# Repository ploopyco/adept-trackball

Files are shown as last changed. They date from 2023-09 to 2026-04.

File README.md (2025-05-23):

# The Ploopy Adept Trackball

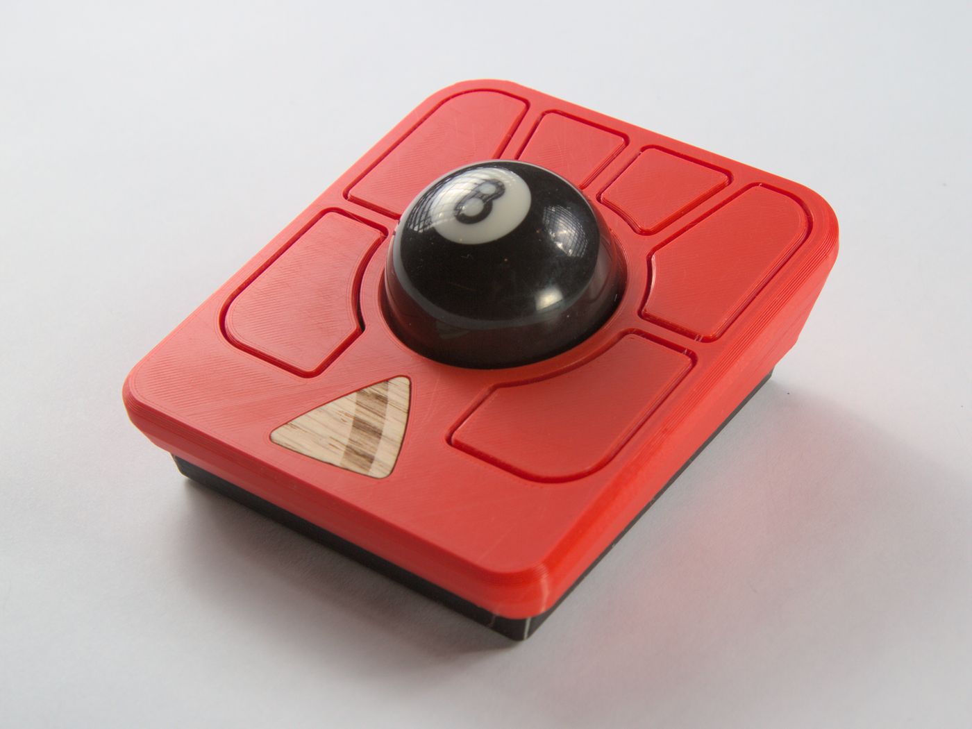
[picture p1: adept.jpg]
The Ploopy Adept Trackball


By some stroke of luck, you've made your way here. The Ploopy Adept Trackball. Your life will never be the same.

This repository contains all of the design and production files necessary to make a Ploopy Adept Trackball. We've also included some [kick-ass documentation](https://ploopyco.github.io/adept-trackball) on how to get it made, assemble it, and program it.

What are you waiting for? Your new life awaits.

## QMK?!

Kits bought from the [Ploopy store](https://ploopy.co/product-category/trackball/adept/) come with QMK and VIA preloaded. [Check out the Wiki](https://ploopyco.github.io/adept-trackball) for instructions on how to load new firmware onto your device. (It's super easy!)

The firmware hex file that ships with all Adepts is included in this repository as well, as `ploopyco_madromys_rev1_001_via.uf2`.

## Under what license is this released?

As per QMK's licensing requirements, the firmware for the Ploopy Adept Trackball is released under GPLv3. Hardware design files, including electronics and mechanical files, are released under OHL CERN v2-S. Check the respective directories for full license text.

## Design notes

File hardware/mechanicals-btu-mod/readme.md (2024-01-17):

## Ploopy Adept BTU Mod by bomtarnes ([keyboard-magpie](https://github.com/keyboard-magpie/))
Included are two print files- 

 - adept-btu-plate.3mf - this includes an integrated support enforcer- I recommend organic supports and "for support enforcers only in prusaslicer
 - adept-btu-top-v1.stl - old fashioned STL for doing as you wish with

Also included is a step file, and a fusion 360 export (my CAD is all self taught and very messy, timeline wise, sorry).

The intended BTUs for v1 are [these veichu ones](https://www.aliexpress.com/item/1005003066404497.html) in 7.5 size.

I am actively working on other versions for other BTU varieties and will aim to add these in the future.

Please do not contact the core ploopy team for any issues with this mod, I can be reached through my github account linked above or on discord.

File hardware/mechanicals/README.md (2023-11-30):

## Only one file? Where are the parts?

The STEP/STL files contain all of the Adept trackball plastic parts in one file. Doing it this way preserves the assembly information, showing how the parts are supposed to fit together, as well as the expected clearances between parts. It also bundles all of the parts for a given revision together, so there's no accidental mixing of parts from different revisions.

## How do I print this?

You'll need to split the parts in the file up before you can print them. Most slicers can do this; if you have a compatible printer we recommend PrusaSlic3r, since that's the one we use in-house and have checked.

Note that submitting this file to some 3rd party print services will cause confusion, as they are expecting one body instead of many. To do this, you can use PrusaSlic3r to split the parts and then export each separately as an STL.

## How can I use the included .3mf file?

The .3mf file was generated using PrusaSlicer v2.5. The job was generated for Prusa i3 MK2S/MK3S/MK3S+ printers. It assumes the use of PLA that is printable at 200-230C. If you have that PrusaSlicer version, such a printer, and such filament, then you're in a lot of luck! We use a .3mf job that is very similar to this one to print Adepts on our printing farm.

If you do not, then using the included .3mf file is likely going to cause you a lot of headaches. If this is the case, the included .3mf file should be considered **as a reference only**. If you use it at all, it is recommended that you look at it to see what kinds of print settings we use (gyroid infill, 0.3mm layer height, part orientation, etc.). However, you should use your own slicing software to generate the .gcode files for your printer.

## Why don't you include a .gcode file?

For your safety. Uploading a .gcode file onto a printer can be extremely hazardous if that .gcode file wasn't specifically generated for that printer. We don't want to come anywhere near that sort of scenario, so we are not going to upload a .gcode file.

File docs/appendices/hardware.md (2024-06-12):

# Appendix C: Hardware

# Buying hardware from us

Getting all of the hardware on your own can be tricky because the parts you select may not fit perfectly. [That's why we sell kits with everything you need to build a Ploopy Adept Trackball](https://ploopy.co/product-category/trackball/adept/). Here's why that's great for you:

- Everything is guaranteed to fit together perfectly
- Everything is guaranteed to work as intended
- You'll end up saving money - probably quite a bit of money - by not spending on extra parts

Your call. You'll sort it out.

# Getting your own hardware

This guide was a bit light on detail in the other sections, and that's because the hardware has to conform to many specifications. They'll all be listed here.

First, a complete list of all the hardware you'll need:

- 4x Small Screws
- 3x MR63ZZ Roller Bearings
- 4x Friction Pads
- 1x Snooker Ball

We'll be going over all of them in detail. There will be mentions of *critical specifications*; if you're going to be sourcing your own parts, **you must get parts that conform to the critical specifications**. If you go off-menu, the parts will not fit the way that we intended when we designed the trackball. That might mean that your trackball **doesn't work**.

Let's get cracking.

## Small Screws

Here are the critical specifications:

- \#2
- 3/8" length

## MR63ZZ Roller Bearings
Here are the critical specifications:

- MR63ZZ bearing
- 3mm inner diameter
- 6mm outer diameter
- 2.5mm thickness

## Friction pads
Here are the critical specifications:

- Circular shape
- Up to 3/4" diameter
- Up to 1/8" thickness
- Non-slip

## Snooker ball
We use 1.75-inch diameter (44.45mm) miniature snooker balls. Any ball between 44.0mm and 44.6mm will work.

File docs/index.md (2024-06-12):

# Home

So, you want to build a Ploopy Adept Trackball, eh? Or, maybe you want to replace some broken parts. Maybe you want to reprogram it. Or maybe you just want to know how it all works. No matter the motivation, this is the place to learn.

**Bought a kit and itching to get it built?** --> Get started by going to the [assembly instructions](assembly-instructions.md).

**Looking to purchase a kit with everything you need to build your own Ploopy Adept?** --> [Check out the Ploopy store](https://ploopy.co/product-category/trackball/adept/).

**Building a Ploopy Adept Trackball from scratch?** --> Get started by going to [Appendix A: Printed circuit boards](appendices/pcbs.md).

---

*Copyright (C) 2023 Ploopy Corporation. Permission is granted to copy, distribute and/or modify this document under the terms of the GNU Free Documentation License, Version 1.3 or any later version published by the Free Software Foundation; with no Invariant Sections, no Front-Cover Texts, and no Back-Cover Texts. A copy of the license is included in the section entitled "GNU Free Documentation License".*

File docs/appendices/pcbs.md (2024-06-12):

# Appendix A: Printed circuit boards

## Buying boards from us
Getting the Ploopy boards made can be complex, and expensive, especially if you only need one set. [That's why we sell kits with everything you need to build a Ploopy Adept Trackball](https://ploopy.co/product-category/trackball/adept/). Here's why that's great for you:

- You get a PCB with all components soldered
- The firmware is already programmed on the microcontroller, so you won't have to program it
- It'll cost a hell of a lot less than if you do a production run of PCBs just for yourself
- You won't have to order components and wait while they come in
- We guarantee that it works

Just something to consider. You're smart. You'll figure it out.

## Making your own boards

Want to make your own Ploopy Adept Trackball boards? Great! Less work for us. Seriously, though, only choose this option if you know what you're doing. You don't want to embarrass yourself, do you?

### Step 1: Order the PCBs from a PCB production company

Here are the most important configurations you'll need to communicate to the company:

- 4 layers
- FR-4, TG 150-160 (basically, whatever the cheapest option is)
- 0.8mm thickness
- 6/6mil track/spacing distance
- 0.3mm minimum hole size
- ENIG surface finish, but you can go with HASL if you don't care about lead poisoning
- 1oz copper thickness for both outer and inner layers
- Choose whatever colours you want for solder mask and silkscreen; we like white solder mask and black silkscreen

If something is missing from here, it's not really important.

At some point, you'll have to upload design files to the production company. Use the [electronics source files](https://github.com/ploopyco/adept-trackball/tree/master/hardware/electronics) to generate manufacturing files (you'll have to convert them from their native Altium format if you're using some other platform). That should contain everything you need to get the boards made. If the production company rejects this package, however, you'll need to address the issue yourself.

### Step 2: Order the electronics components

All of the components are described in the schematics of the PCBs. Ordering the components is left as an exercise for the reader.

A complete list of all of the components can be found in the electrical design files.

### Step 3: Get the necessary tools

- PCB
- All of the electronics components
- A soldering iron
- Solder
- A printout of the schematics

### Step 4: Solder the components to the boards

Once you've got the PCBs and all of the components, print out the schematics. Use the schematics to match the reference designators on the PCBs to the reference designators on the schematics, and then get to soldering.

If you've never soldered surface mount components before, or want a refresher on how to solder, we recommend [this video on using an iron to solder surface mount components](https://www.youtube.com/watch?v=3NN7UGWYmBY), and [this video on using a hot-air soldering station](https://www.youtube.com/watch?v=c_Qt5CtUlqY).

Lastly, you'll need to follow a set of special instructions to assemble the PMW3360 sensor and the optic. [Take a look at page 11 of the official PMW3360 datasheet to find out how to do this](https://d3s5r33r268y59.cloudfront.net/datasheets/9604/2017-05-07-18-19-11/PMS0058-PMW3360DM-T2QU-DS-R1.50-26092016._20161202173741.pdf) (page 8 has visuals, for those of you who like purdy pictures).

**MAKE SURE THAT THE PMW3360 IS ORIENTED CORRECTLY BEFORE YOU SOLDER IT!** This is a really easy step to mess up, so *DOUBLE-CHECK IT!*

### Step 5: All done!

Congrats, you finished assembling the electronics! Pat yourself on the back.

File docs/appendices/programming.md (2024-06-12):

# Appendix D: QMK Firmware Programming

# Working with QMK

Ploopy devices are fairly easy to program and reprogram, thanks to the excellent work by all of the developers and maintainers of the [QMK firmware suite](https://github.com/qmk/qmk_firmware).

## Madromys? What's that?

`madromys` is our internal codename for the Ploopy Adept. We don't always know what we're going to call the devices as we're designing them, so we assign codenames to them. This naming convention is also present in some public places, such as the QMK repository. If you see `madromys` while you're working with QMK, just know that the Adept and `madromys` are the same thing.

## Before you begin

If you have never used QMK before, go through [all of the steps in the QMK guide to set up your environment](https://docs.qmk.fm/#/newbs_getting_started).

QMK was built for keyboards, so you'll see lots of references to code that looks like the following:

`-kb <keyboard>`

Whenever you see that, use the following syntax:

`-kb ploopyco/madromys/rev1_001`

and you'll be fine.

## Building the Ploopy device firmware

With your terminal window open and pointed at your QMK build environment, compile the firmware with the following command:

`qmk compile -kb ploopyco/madromys/rev1_001 -km via`

Alternatively, you can invoke the Makefile directly with the following:

`make ploopyco/madromys/rev1_001:via`

If you wish, you can use the default keymap (with `qmk compile -kb ploopyco/madromys/rev1_001 -km default` or `make ploopyco/madromys/rev1_001:default`). However, the VIA keymap is particularly interesting because it allows for customization of the trackball's functions without reflashing the firmware, through the use of the convenient [VIA software package](https://github.com/the-via/releases/releases). It's incredibly handy, so definitely check it out.

For more details on building QMK firmware in general, see the [QMK firmware guide](https://docs.qmk.fm/#/newbs_building_firmware).

## Putting the Ploopy device into bootloader mode

Putting the Ploopy device into bootloader mode is very easy.

1. Unplug it from your computer.
2. Hold down the Bottom Left button on the Adept.
3. Plug the Ploopy device into your computer.
4. The computer should recognise that a mass storage device was just plugged in. Once this is done, you should be able to drag and drop files onto the Ploopy device, as if the board was a USB drive. Feel free to remove the tweezers or paperclip at this point.

And that's it. While plugged in this way, the Ploopy device will accept new firmware.

If you want to upload a new firmware file (a ".uf2" file, like "ploopy_adept_v42069" or something), just drag it into the folder, and it'll automatically install on the Ploopy device and restart itself.

Whenever you want to put new firmware onto the Ploopy device, go through these steps again.

**TIP**: If your firmware is in some kind of strange state and uploading new firmware isn't fixing it, try uploading [a flash nuke](https://learn.adafruit.com/getting-started-with-raspberry-pi-pico-circuitpython/circuitpython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) to the Adept before flashing the new firmware. It wipes the memory of the Adept completely clean, which can help clear a few types of errors.

## Putting the Ploopy device into bootloader mode if it's bricked

Putting the Ploopy device into bootloader mode if it's bricked is a bit more involved, but still doable.

1. Unplug it from your computer.
2. Open it by removing the screws in the base and removing the top.
3. Look for a pair of vias (gold-plated holes) on the board. You can see where they're located [in this photo](https://ploopy.co/wp-content/uploads/2023/11/boot.jpg).
4. Get a paper clip (non-insulated, i.e. no plastic shit covering it) or a pair of tweezers, or some wire. Whatever you've got on hand that's metal.
5. Stick the paper clip or tweezers into the holes. You're trying to form an electrical connection between the two holes.
6. While you've got the two vias connected with your metal bridge, plug the Ploopy device into your computer.
7. The computer should recognise that a mass storage device was just plugged in. Once this is done, you should be able to drag and drop files onto the Ploopy device, as if the board was a USB drive. Feel free to remove the tweezers or paperclip at this point.

And that's it. While plugged in this way, the Ploopy device will accept new firmware.

## And that's it!

Happy customizing!

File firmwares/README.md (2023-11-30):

## What is "drag_scroll_click_and_hold" vs. "drag_scroll_toggle"?

Each directory contains a type of firmware. For "click_and_hold", the drag scroll functionality works by clicking and holding the drag scroll button.

For "toggle", the drag scroll functionality works by clicking to turn on the drag scroll, and clicking again to turn it off.

## What is "semaphore_X"?

That is a notation of how sensitive the drag scroll is.

"semaphore_8" is the **least sensitive** drag scroll. That means, you'll have to move the ball more to scroll.

"semaphore_0" is the **most sensitive** drag scroll. That means, you'll have to move the ball less to scroll.

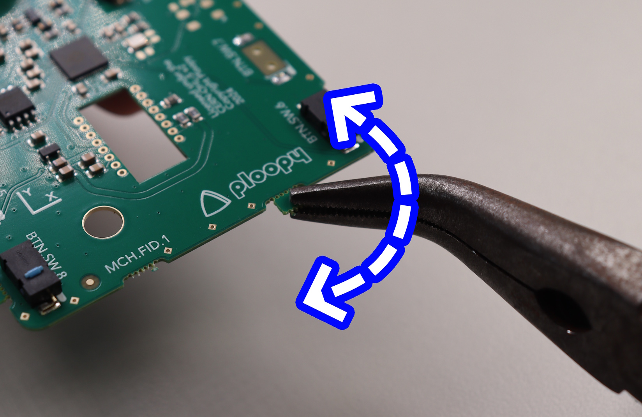
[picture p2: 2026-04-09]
docs/assets/2b.jpg

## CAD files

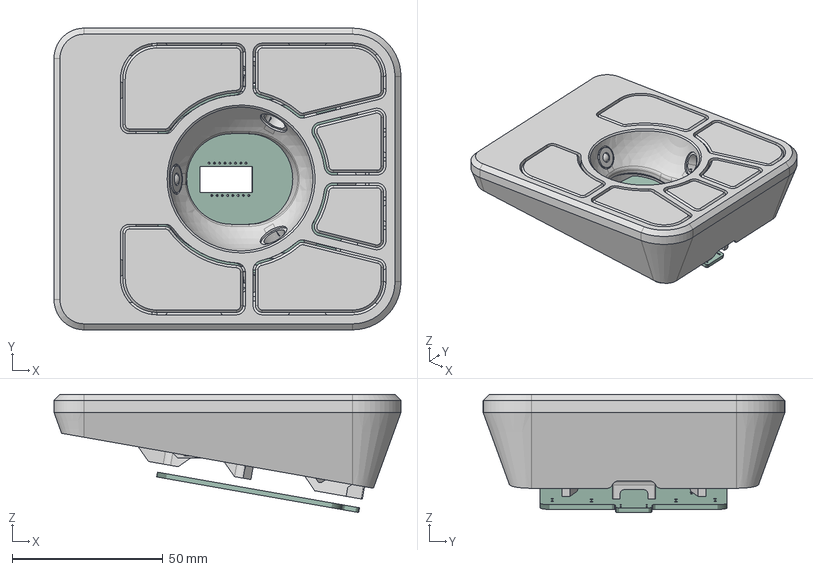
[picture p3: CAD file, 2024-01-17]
hardware/mechanicals-btu-mod/adept-btu-top-v1.step
115.0 x 100.0 x 39.1 mm
BTU Copy
AdeptBodyParts v1
Madromys_PCB

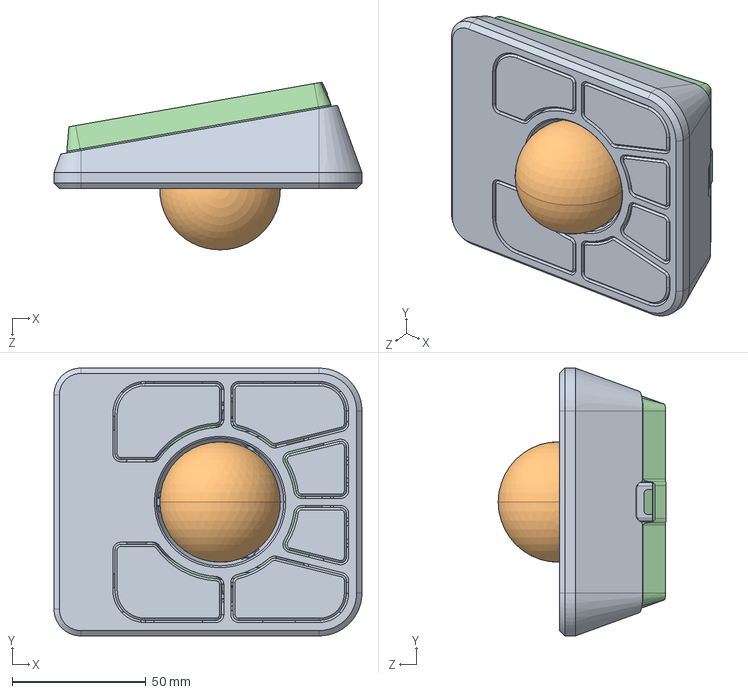
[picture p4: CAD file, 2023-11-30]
hardware/mechanicals/STEPs/Adept-Rev3.STEP
115.0 x 100.0 x 62.6 mm

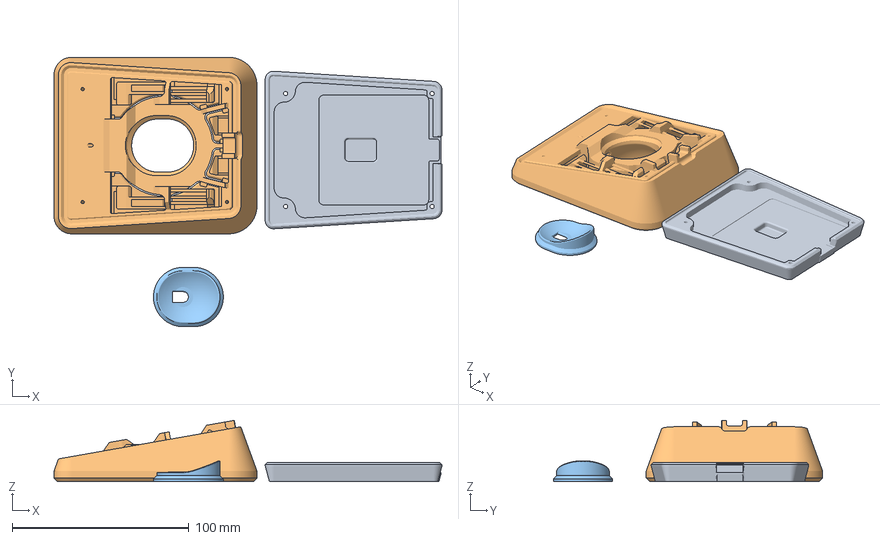
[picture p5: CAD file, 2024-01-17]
hardware/mechanicals-btu-mod/adept-btu-plate.3mf
219.8 x 152.6 x 34.7 mm
base.stl
topshell.stl
sensor insert.stl

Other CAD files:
hardware/mechanicals-btu-mod/adept-btu-top-v1.f3z
hardware/mechanicals-btu-mod/adept-btu-top-v1.stl
hardware/mechanicals/Adept-Rev3.3mf

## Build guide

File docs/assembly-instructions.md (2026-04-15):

<style>
  body {
    font-size: 50px;
  }
</style>

## Step 1: Prepare necessary tools

<p align="center">
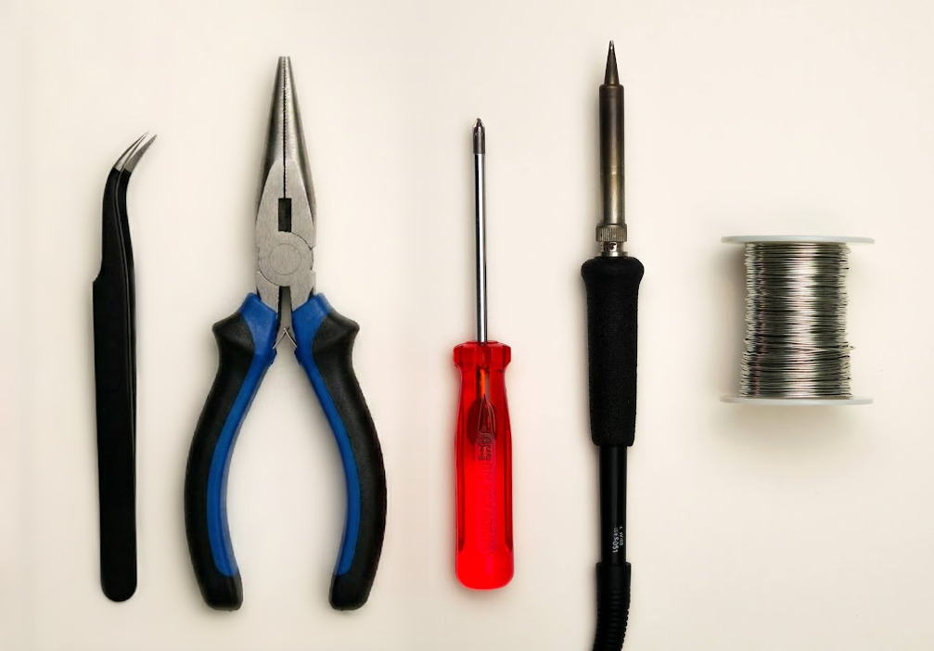
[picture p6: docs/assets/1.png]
  
</p>

- A #1 Phillips head screwdriver
- Soldering iron
- Solder
- Optional: tweezers
- Needle-nose pliers

<div style="background-color: #fcf003; color: #333; padding: 15px; border-radius: 5px; margin-bottom: 10px; display: flex; align-items: center;">
  <span style="font-size: 20px; margin-right: 10px;">💡</span>
  <div>
    <strong>Tip:</strong> A similar smallish Phillips head screwdriver could work.
  </div>
</div>

## Step 2: Break off possible leftover tabs off the PCB
- There are up to six possible small tabs along the edge of the PCB as shown in the picture.
- Holding the PCB as pictured, gently break off any tabs using a pair of pliers.

<div style="background-color: #ffb3b3; color: #333; padding: 15px; border-radius: 5px; margin-bottom: 10px; display: flex; align-items: center;">
  <span style="font-size: 20px; margin-right: 10px;">🚨</span>
  <div>
    <strong>Warning:</strong> These tabs should come off relatively easily, don’t use excessive force, it probably means you are doing it wrong!
  </div>
</div>

<p align="center">
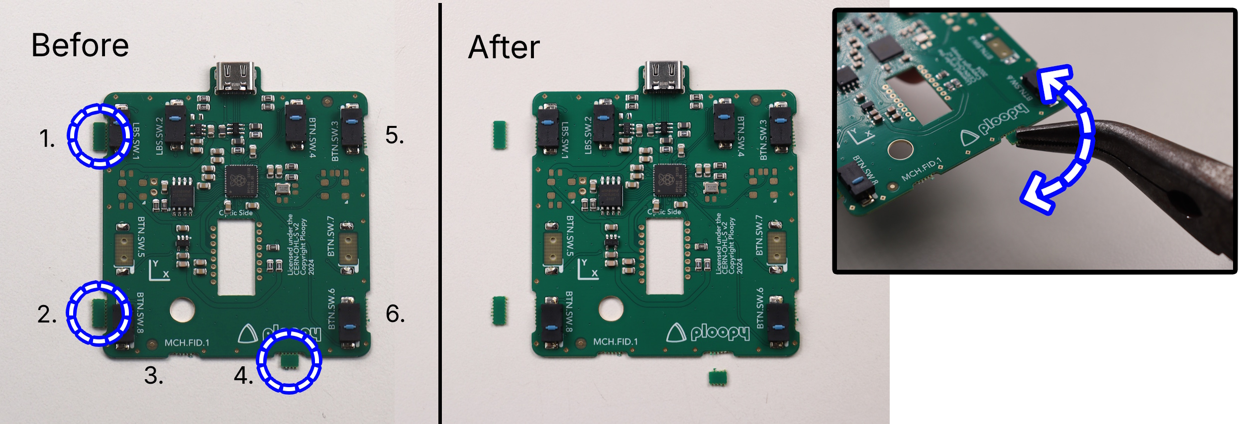
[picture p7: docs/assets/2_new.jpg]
  
</p>

## Step 3: Prepare parts for PCB soldering

Prepare the following components as pictured below:

- Printed circuit board
- PMW-3360 chip

<div style="background-color: #fcf003; color: #333; padding: 15px; border-radius: 5px; margin-bottom: 10px; display: flex; align-items: center;">
  <span style="font-size: 20px; margin-right: 10px;">💡</span>
  <div>
    <strong>Tip:</strong> The PMW-3360 chip will come in a small piece of foam. Go ahead and remove it now.
  </div>
</div>

<p align="center">
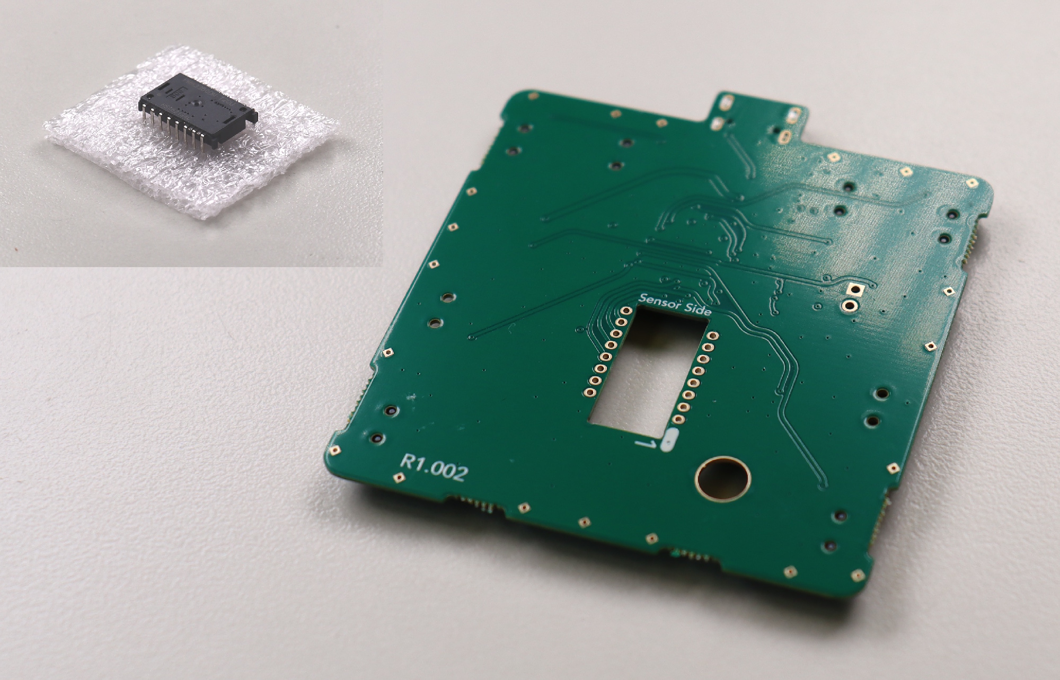
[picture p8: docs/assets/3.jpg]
  
</p>

## Step 4: Solder PMW-3360 sensor to printed circuit board

- Place the sensor onto the circuit board, ensuring the orientation is correct.

<div style="background-color: #ffb3b3; color: #333; padding: 15px; border-radius: 5px; margin-bottom: 10px; display: flex; align-items: center;">
  <span style="font-size: 20px; margin-right: 10px;">🚨</span>
  <div>
    <strong>Warning:</strong> Use the cues presented in the following images to ensure the sensor is oriented correctly.
  </div>
</div>

<p align="center">
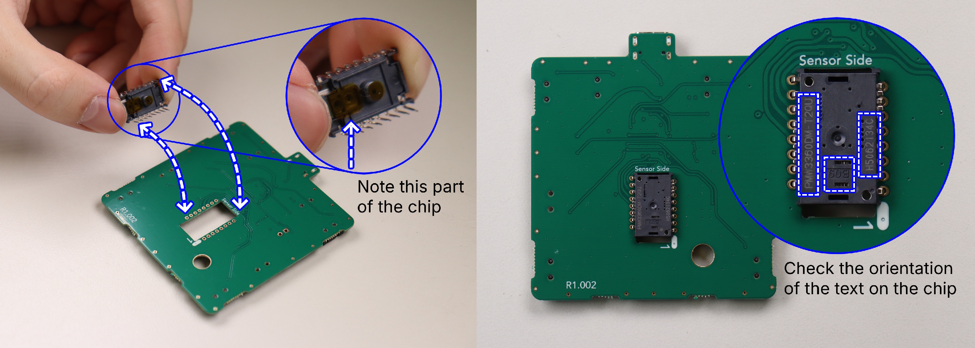
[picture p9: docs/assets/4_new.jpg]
  
</p>

<div style="background-color: #ffb3b3; color: #333; padding: 15px; border-radius: 5px; margin-bottom: 10px; display: flex; align-items: center;">
  <span style="font-size: 20px; margin-right: 10px;">🚨</span>
  <div>
    <strong>Warning:</strong> The sensor must be flat down as far as it can possibly slide into the holes before soldering.
  </div>
</div>

<p align="center">
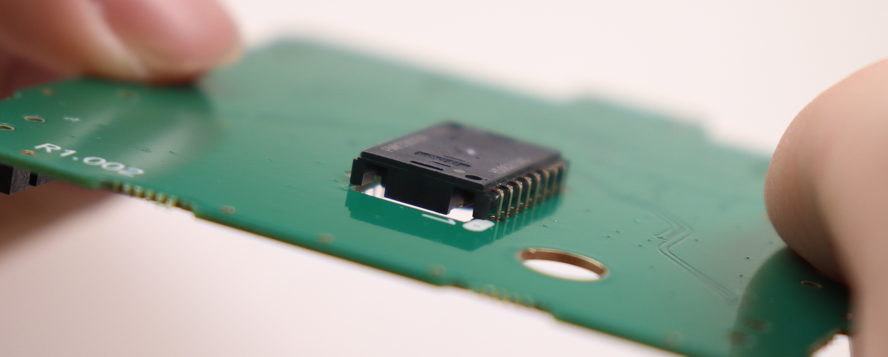
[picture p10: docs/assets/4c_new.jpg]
  
</p>

## Step 5: Remove the tab of kapton tape on the PMW-3360 chip

<div style="background-color: #fcf003; color: #333; padding: 15px; border-radius: 5px; margin-bottom: 10px; display: flex; align-items: center;">
  <span style="font-size: 20px; margin-right: 10px;">💡</span>
  <div>
    <strong>Tip:</strong> Try to do this step in a dust-free environment.
  </div>
</div>

- There are two small tabs of orange tape covering the sensor's main holes. Remove them now.

<p align="center">
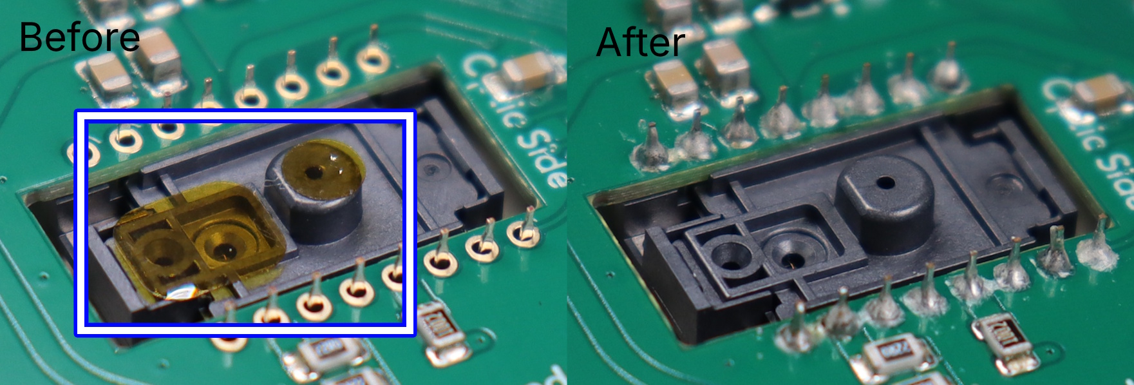
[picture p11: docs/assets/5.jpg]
  
</p>

<div style="background-color: #cce5ff; color: #004085; padding: 15px; border-radius: 5px; margin-bottom: 10px; display: flex; align-items: center;">
  <span style="font-size: 20px; margin-right: 10px;">ℹ️</span>
  <div>
    <strong>Info:</strong> Check your solder joints during this step to ensure that they are good. To know if they are good, consult the
    <a href="https://help.ploopy.co/?docs=ive-soldered-my-kit-together-but-the-parts-i-soldered-dont-work-2" style="color: #004085; font-weight: bold; text-decoration: underline;">soldering FAQ</a>.
  </div>
</div>

## Step 6: Attach the PMW-3360 optic to the PMW-3360 chip

- Orient the optic as shown in the image before insertion.

<div style="background-color: #ffb3b3; color: #333; padding: 15px; border-radius: 5px; margin-bottom: 10px; display: flex; align-items: center;">
  <span style="font-size: 20px; margin-right: 10px;">🚨</span>
  <div>
    <strong>Warning:</strong> It should NOT require any force to insert fully; if it does, remove it and check the orientation before trying again.
  </div>
</div>

<p align="center">
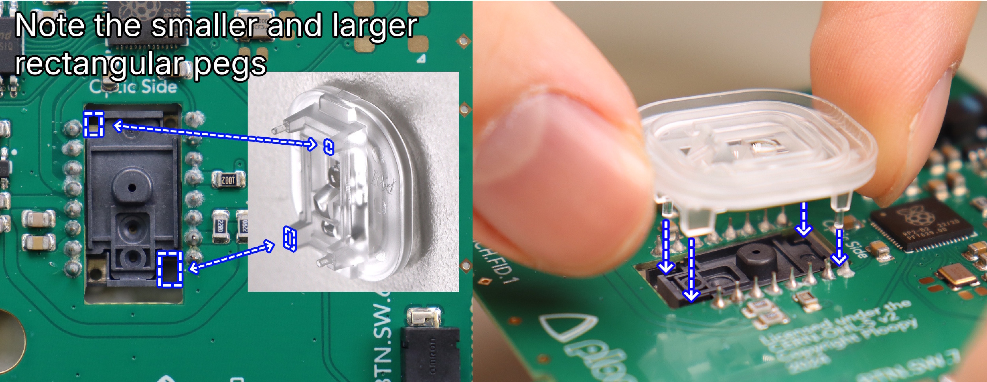
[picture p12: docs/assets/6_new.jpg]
  
</p>

## Step 7: Place the PCB into the Base

- This should be straightforward, the PCB should fit exactly as shown.

<p align="center">
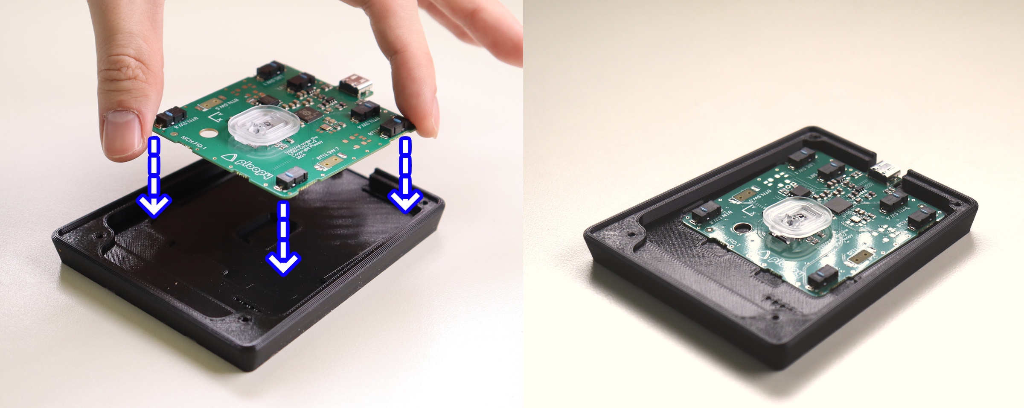
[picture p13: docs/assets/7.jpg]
  
</p>

## Step 8: Place the Sensor Cap on the PCB

- Place the sensor cap on the PCB as shown in the image.

<div style="background-color: #fcf003; color: #333; padding: 15px; border-radius: 5px; margin-bottom: 10px; display: flex; align-items: center;">
  <span style="font-size: 20px; margin-right: 10px;">💡</span>
  <div>
    <strong>Tip:</strong> The Sensor Cap doesn't snap onto the PMW-3360 optic. It "floats" on top of the optic for now. Once fully assembled, the Sensor Cap will be securely held down.
  </div>
</div>

<p align="center">
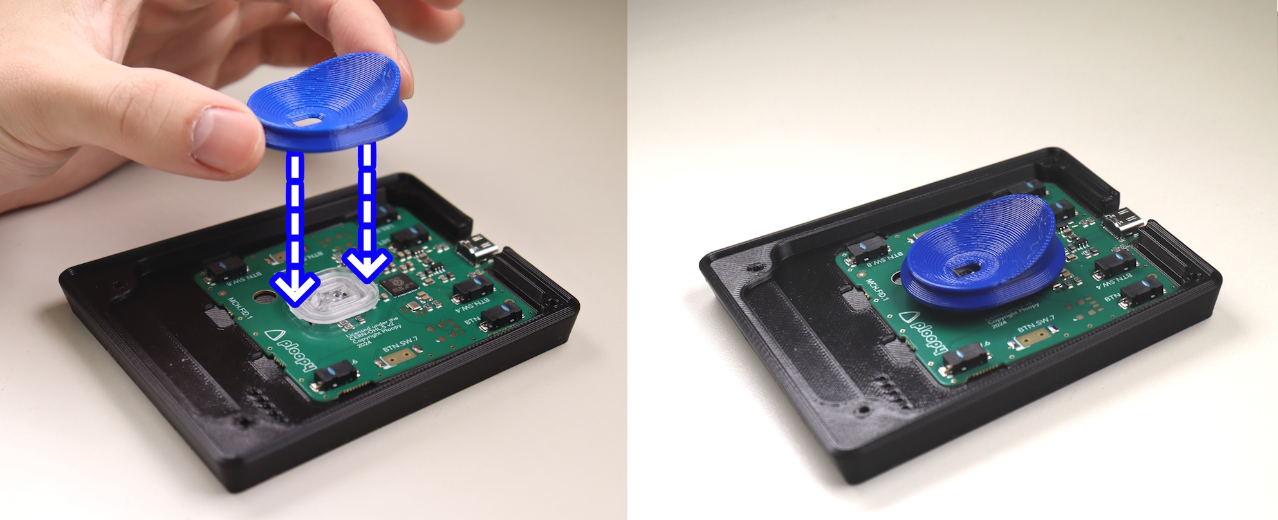
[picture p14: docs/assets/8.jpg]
  
</p>

## Step 9: Place the Top Piece onto the Base Piece

- Place the top onto the base.

<p align="center">
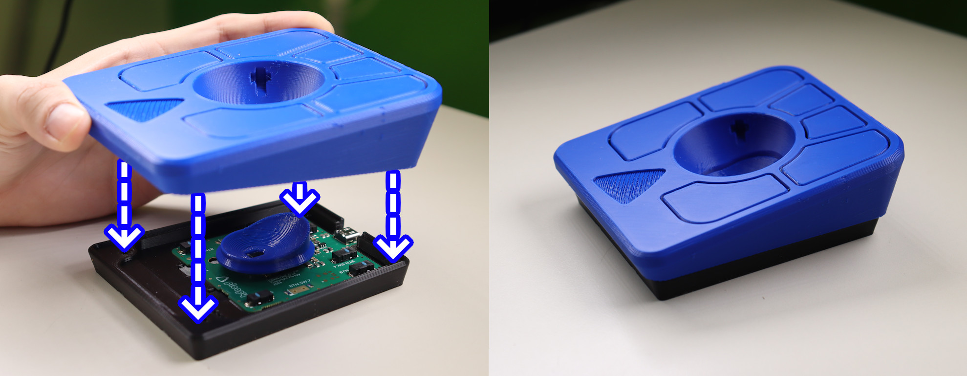
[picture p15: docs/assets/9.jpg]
  
</p>

<div style="background-color: #fcf003; color: #333; padding: 15px; border-radius: 5px; margin-bottom: 10px; display: flex; align-items: center;">
  <span style="font-size: 20px; margin-right: 10px;">💡</span>
  <div>
    <strong>Tip:</strong> If necessary, adjust the position of the Sensor Cap as you're lowering the Top onto the Base. It should end up looking like the image.
  </div>
</div>

<p align="center">
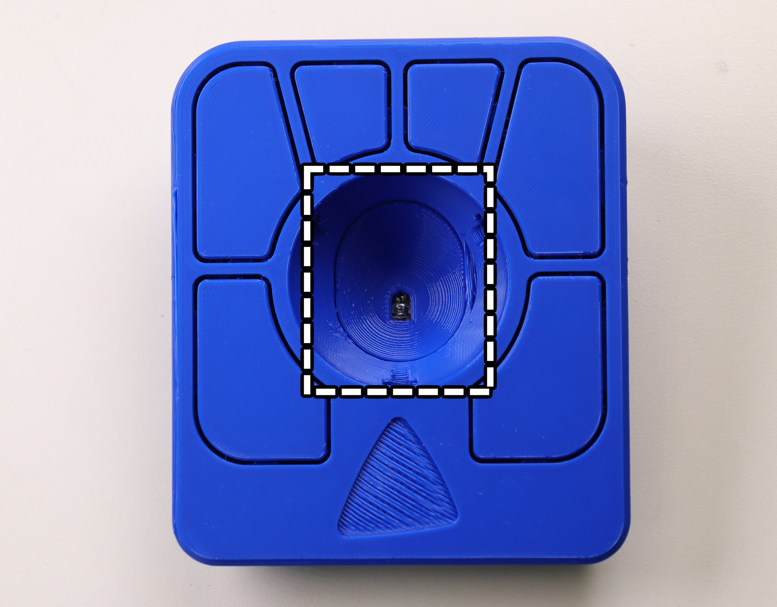
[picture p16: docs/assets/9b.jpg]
  
</p>

## Step 10: Screw the Base into the Top

<div style="background-color: #fcf003; color: #333; padding: 15px; border-radius: 5px; margin-bottom: 10px; display: flex; align-items: center;">
  <span style="font-size: 20px; margin-right: 10px;">💡</span>
  <div>
    <strong>Tip:</strong> You are safe to flip the frame upside down for this and future steps.
  </div>
</div>

- Slowly drive the screws into the four holes in the top until you feel resistance.

<div style="background-color: #ffb3b3; color: #333; padding: 15px; border-radius: 5px; margin-bottom: 10px; display: flex; align-items: center;">
  <span style="font-size: 20px; margin-right: 10px;">🚨</span>
  <div>
    <strong>Warning:</strong> Only screw until the frame feels firmly together. If you use too much force, you may break the frame.
  </div>
</div>

<p align="center">
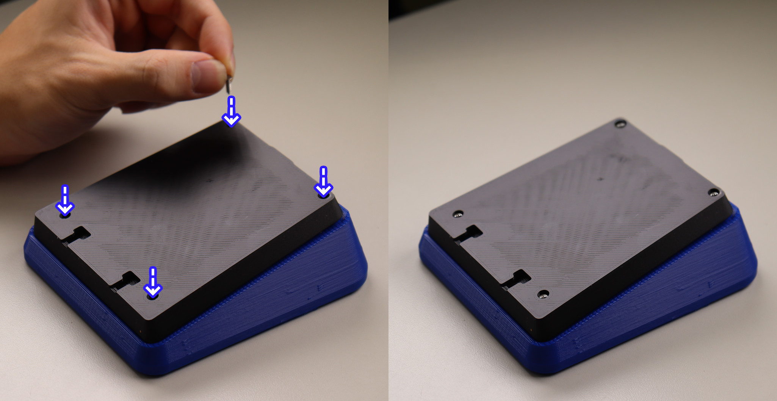
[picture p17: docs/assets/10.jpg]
  
</p>

## Step 11: Prepare Roller Bearing Parts

- 3x Roller Bearing
- 3x Roller Bearing Dowel
- Bearing Press Jig (Taller Half + Shorter Half)

<p align="center">
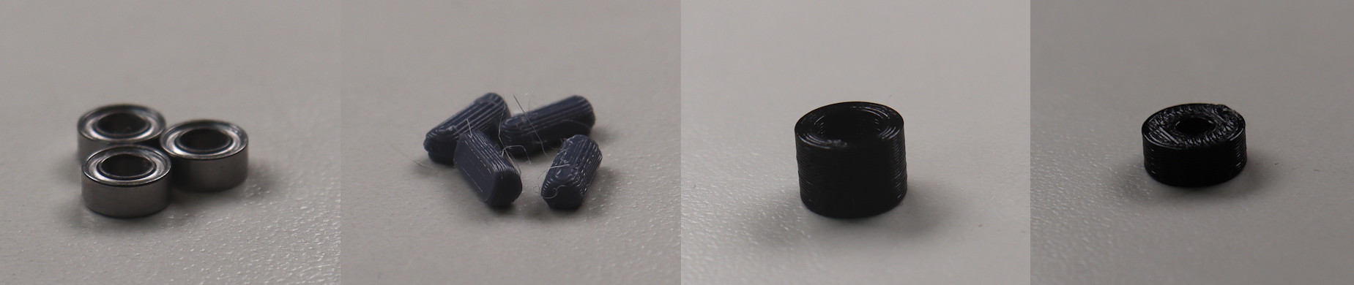
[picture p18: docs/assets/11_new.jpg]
  
</p>

## Step 12: Insert Roller Bearing and Bearing Dowel into Bearing Press Jig

- Insert the bearing into the taller half of the bearing press jig.

<p align="center">
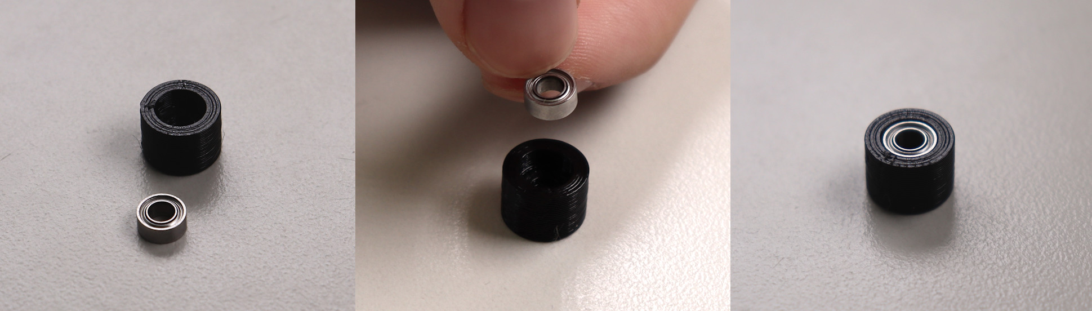
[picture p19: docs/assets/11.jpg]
  
</p>

- Insert dowel into the shorter half of the bearing press jig.

<p align="center">
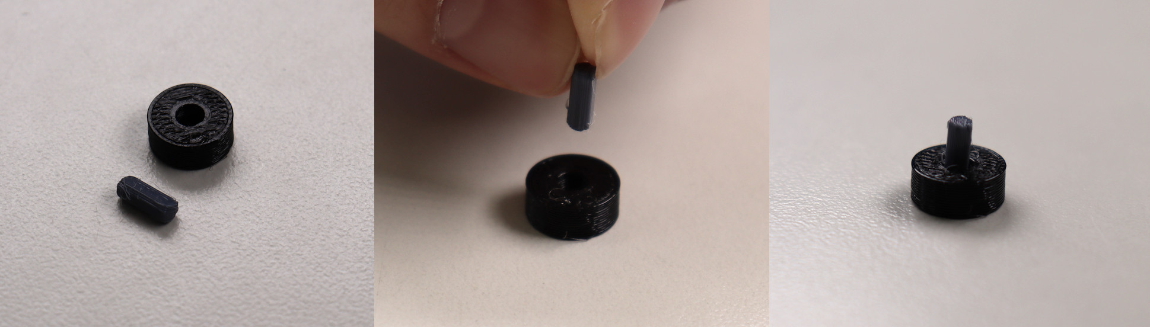
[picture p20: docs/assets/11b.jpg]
  
</p>

## Step 13: Press the Bearing Jig Together

- Press the bearing press jig together.

<div style="background-color: #ffb3b3; color: #333; padding: 15px; border-radius: 5px; margin-bottom: 10px; display: flex; align-items: center;">
  <span style="font-size: 20px; margin-right: 10px;">🚨</span>
  <div>
    <strong>Warning:</strong> This may require a surprising amount of force; try your best not to bend the roller bearing dowel. If you do, there are spares included in the assembly kit.
  </div>
</div>

<p align="center">
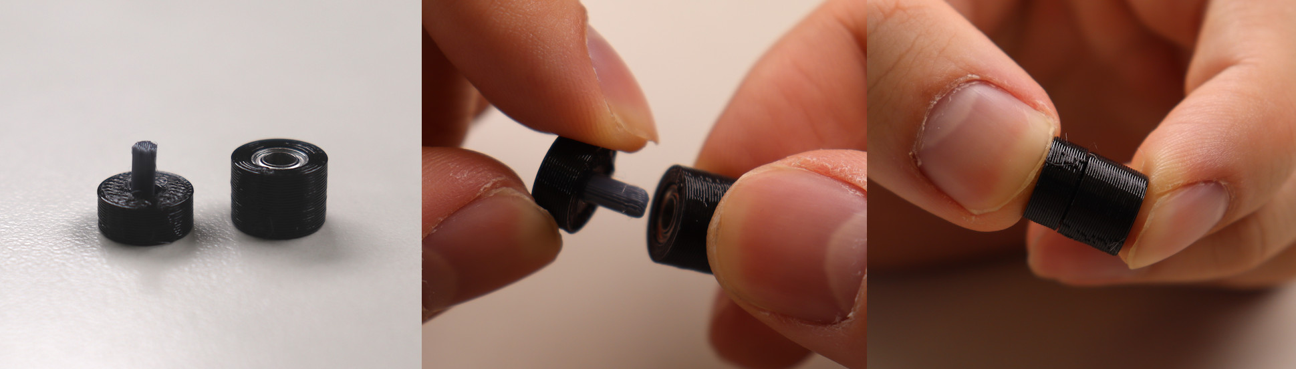
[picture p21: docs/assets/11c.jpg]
  
</p>

## Step 14: Remove roller bearing from bearing press jig and repeat

- Remove the the roller bearing from the press jig.
- Repeat 3 times to end with 3 roller bearings.

<p align="center">
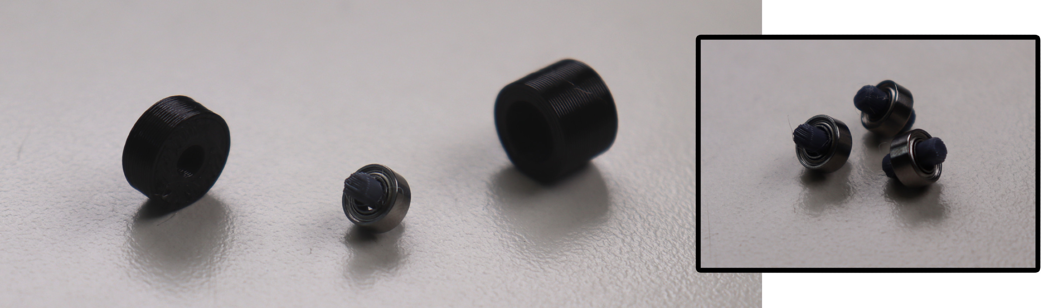
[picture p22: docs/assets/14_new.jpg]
  
</p>

## Step 15: Insert roller bearings into the Top Piece

- Insert the roller bearings into the 3 holes in the top of the frame.
- Ensure the bearings are pressed all the way into the case.

<div style="background-color: #fcf003; color: #333; padding: 15px; border-radius: 5px; margin-bottom: 10px; display: flex; align-items: center;">
  <span style="font-size: 20px; margin-right: 10px;">💡</span>
  <div>
    <strong>Tip:</strong> Needle nose pliers or some similar tool can be used to ensure that the bearing is fully seated.
  </div>
</div>

<p align="center">
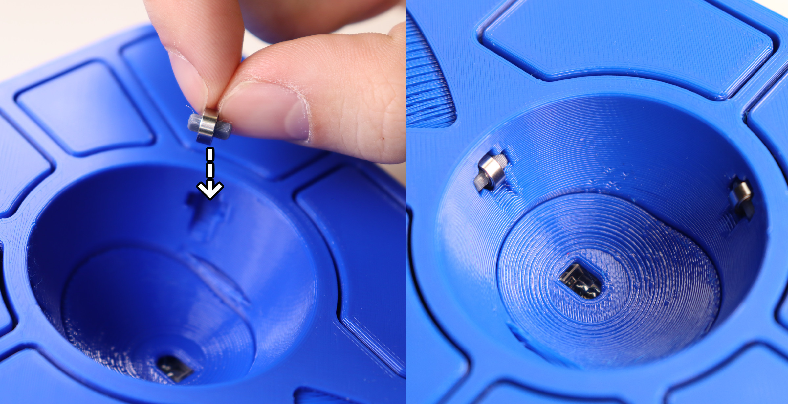
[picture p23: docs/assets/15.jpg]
  
</p>

<div style="background-color: #ffb3b3; color: #333; padding: 15px; border-radius: 5px; margin-bottom: 10px; display: flex; align-items: center;">
  <span style="font-size: 20px; margin-right: 10px;">🚨</span>
  <div>
    <strong>Warning:</strong> If the bearings aren't seated all the way, there's a good chance that the ball will become badly scratched.
  </div>
</div>

## Step 16: Place Friction Pads on Base

- Flip the adept frame upside down.
- Place the friction pads on each corner of the frame.

<div style="background-color: #fcf003; color: #333; padding: 15px; border-radius: 5px; margin-bottom: 10px; display: flex; align-items: center;">
  <span style="font-size: 20px; margin-right: 10px;">💡</span>
  <div>
    <strong>Tip:</strong> Do your best not to cover the screw holes with the friction pads, as this will make opening the case more difficult in the future.
  </div>
</div>

<p align="center">
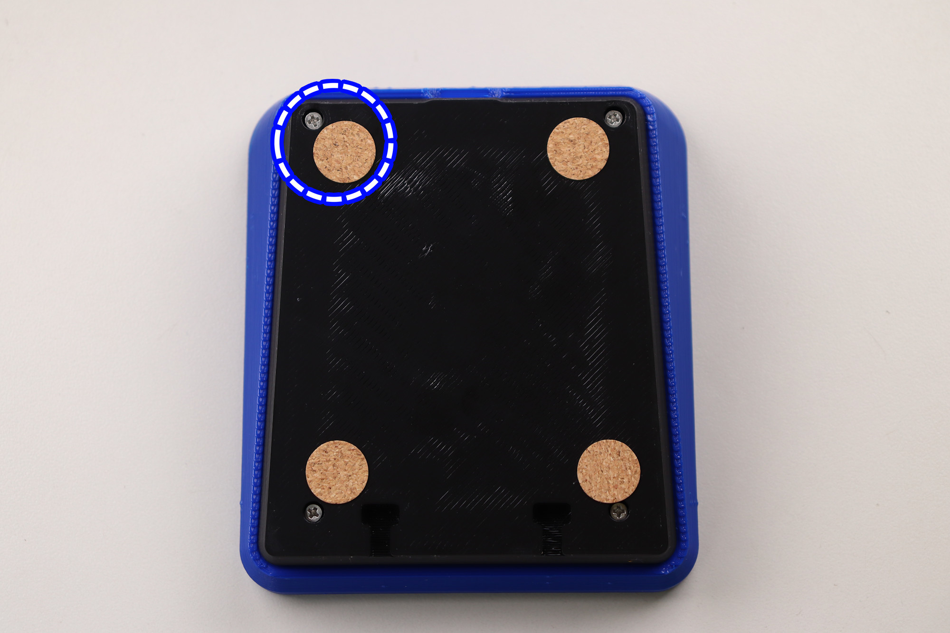
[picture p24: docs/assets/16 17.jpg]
  
</p>

## Step 17: Insert the ball

- Insert the track ball into the hole in the middle of the adept frame.

<p align="center">
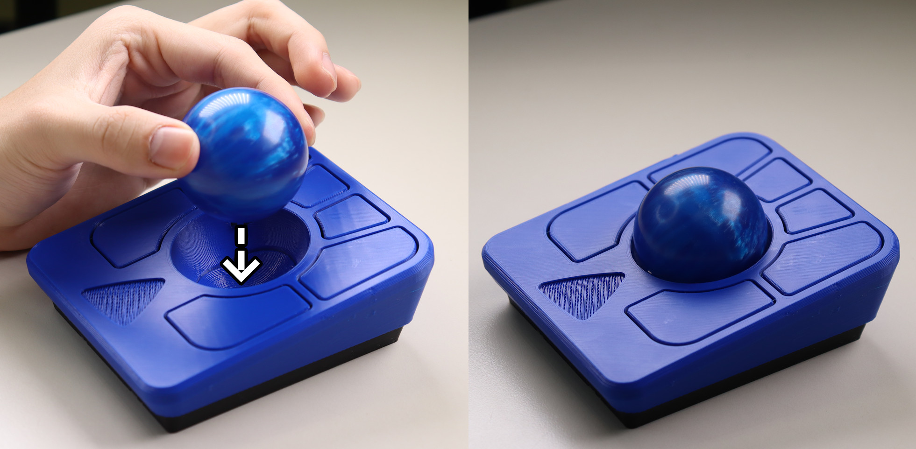
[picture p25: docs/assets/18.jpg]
  
</p>

## Step 18: Peel and stick the logo to the Top

- Insert the logo in the indent on the top of the frame.

<p align="center">
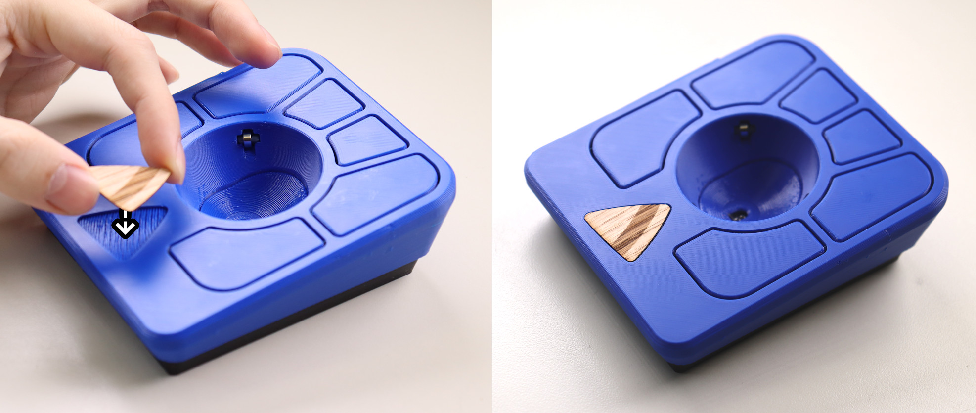
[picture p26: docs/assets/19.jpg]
  
</p>

## Step 19: All done!

<p align="center">
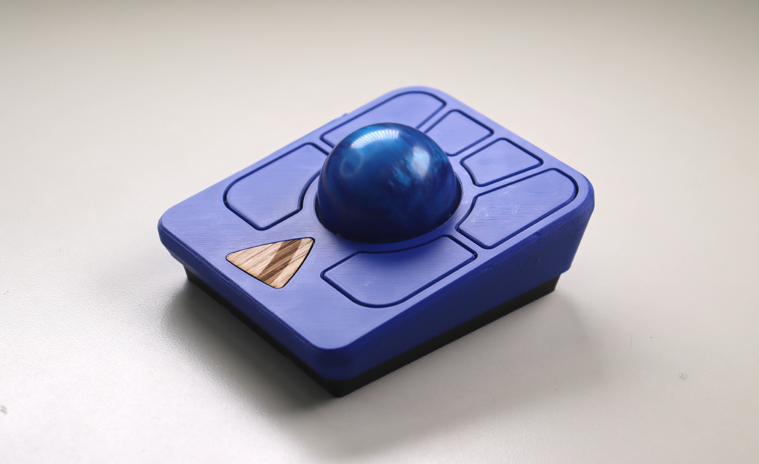
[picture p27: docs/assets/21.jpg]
  
</p>

## Post Steps:

### Spin the ball to break in the bearings
- Spin the ball around for around 3 minutes to break them initially before any use
- The bearings may take around a week to become fully broken-in/smooth

### Verify the Ploopy Adept Trackball is working correctly
- Plug the adept trackball mouse into the computer using a USB-C cable
- Move the ball around, it should move the cursor

### Check out Post Build FAQ
- [Post Build FAQ](https://help.ploopy.co/?docs=where-can-i-find-mods-for-my-ploopy-device)
- Contains various information about things you can do after initial assembly!

<div style="background-color: #cce5ff; color: #004085; padding: 15px; border-radius: 5px; margin-bottom: 10px; display: flex; align-items: center;">
  <span style="font-size: 20px; margin-right: 10px;">ℹ️</span>
  <div>
    <strong>Info:</strong> If the trackball is not working, consult our
    <a href="https://help.ploopy.co/checklist-v2/" style="color: #004085; font-weight: bold; text-decoration: underline;">troubleshooting guide</a>
    for further steps.
  </div>
</div>

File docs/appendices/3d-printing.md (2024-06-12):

# Appendix B: 3D printed parts

# Buying 3D-printed parts from us
Not everyone has access to a 3D-printer. [That's why we sell kits with everything you need to build a Ploopy Adept Trackball](https://ploopy.co/product-category/trackball/adept/). Here's why that's great for you:

- You get all of the 3D-printed parts, guaranteed free of manufacturing defects
- You won't waste time spending hours tweaking settings
- We guarantee it will fit together *perfectly*

Consider it. You're a smartie. You'll get there.

# Printing your own parts

So, you have a printer and want to print your own parts? Great! We don't have specific instructions, since every printer setup is different. All of the STLs are available, and if you need to make tweaks, you can alter the design files.

Here are the settings we use when we print parts. **Note that these settings have only been tested on the Prusa i3 MK2.5S and MK3S.** If you have another printer, you may need to tweak these settings.

- PLA. The geometry of many of the parts is quite complex; trying to use other materials may not result in success.
- 0.30mm layer height. You can go finer than this if you want, but we haven't tested that. Going coarser is not going to work; first, it's going to feel rough on your hand, and second, it won't accurately capture the necessary detail.
- No support material is required anywhere. However, your printer must have the capability of bridging distances of up to 40mm.
- Orient the pieces so that flat sides are on the build plate.
- We like gyroid for infill pattern, but anything is probably good. Cubic, rectilinear, whatever.
- We use 0.4mm nozzles. We haven't tested other nozzle sizes.

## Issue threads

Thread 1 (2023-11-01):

Scale/alter for other size of ball

dwillmore, 2023-11-01:
I love this project.  I've wanted to make my own trackball for a long time.  I originally wanted to make one with an undrilled bowling ball, but I've never been able to source a ball without some kind of manufacturers logo engraved in it.  I have an old logitech trackball that I very gently nicked the ball by dropping it once, and I know how much even a tiny imperfection in the ball makes the experience unplesant.

But this seems quite reasonable (unlike my idea).  But, I'm in the USA and snooker isn't really a game here.  We have lots of billiards supplies, but the balls are 2.25".  Any suggestions on how I could go about adapting this design to accomodate the larger size of ball?  Naively, I could scale it up by 9/7 and try to adapt the remaining parts to fit, but that seems problematic as all the bearings, screws, switch mounts, etc. will not take kindly to that.

Thank you for everything!

dwillmore, 2023-11-01:
Optionally, it seems like it's relatively easy to source a 1.75" steel bearing.  My concern would be that the surface would be too smooth to track--not that a little bit of sandpaper couldn't solve that in short order.  Anyone see concerns with the added mass/inertia of using a steel ball instead of a resin one?

jwGreys, 2023-11-03:
I recently picked up a G100-1 Bearing off Amazon at 44.45mm (1.75") and so far it's working fairly well for me.  There was some skipping at first (on fast movements) but after it got smudged up with fingerprints a bit it has been a blessing for my personal preference.  The added mass really gives me a feeling of more control on the cursor.

itsnoteasy, 2023-11-25:
I have managed to fit a 57.2mm ball to the adept stl. what i did was scaled the stl up in a 45:55 ratio. Then i took a 2mm drill bit and drilled three shallow holes beside the ball bearing mount. I then pressed in a 2.5mm zirconium bearing in each hole. I used the rp2040 trackball pcb by jfedor since i already had it, and hotglued it and switches into position.

Closed 2023-11-30.

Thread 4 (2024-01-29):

DIY print files - no place for veneer, no PLOOPY text, PCB won't fit

jameswood, 2024-01-29:
The DIY 3D print files have no "PLOOPY" text and, no space for the wooden veneer accent piece. I thought this might have been deliberate for the print-it-yourself versions, but then the kit arrived with the veneer piece included.

PCB does not fit into the space allowed (this could be my printer overextruding!)

radekw, 2024-01-29:
I printed mine on Bambu P1S in PLA-CF (looks amazing). I can't try on Prusa as it's broken at the moment. My PCB fits fine, but I noticed another issue - when I put it together all buttons are pressed - I added 3 layers of electrical tape to space the top and bottom apart and only then the buttons started clicking fine. This could also be attributed to a different printer or a filament. Otherwise, love the trackball!

ChiefGyk3D, 2024-03-24:
I just printed mine and noticed it was missing as well and kind of was disappointed

Spartin996, 2024-03-29:
I was hopeing to find it so that I could try and invert it.

My little veneer came out so I was going to try and print a blank to slot in, just so that it is not a solid colour.

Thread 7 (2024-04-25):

Wiki link for programming is missing

robws, 2024-04-25:
Adept main Readme.md missing wiki link for " Check out the Wiki for instructions on how to load new firmware onto your device. (It's super easy!)"

Happy to update the readme.md with contribution instructions if I can get that link.

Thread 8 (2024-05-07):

Project files for 3d printing?

githubforced2fabad, 2024-05-07:
I would like to create a parameterized version of the adept. Input ball size, and the whole thing scales to fit the ball. Of course some things will need to remain constantly sized such as the the slots for the rollers, the hole for the sensor, the hole for the usb-c port, holes for the screws, and the space for the computer chip. In addition the buttons will have to extend further to reach the static location of the buttons on the computer chip.

My reasoning is that I would like to have to adept but with a larger ball.

Anyway, I am totally new to 3d printing design. I was successfully able to separate the 3 parts (top, bottom, and what I'm calling the cradle (the part with the hole for the sensor)). It seems like the parts are rather blob-like as in there is no properties on them to change (I'm using free cad). From my reading online, I would need the original project files to do this kind of work (as opposed to the STL files).

Any advice would be much appreciated.

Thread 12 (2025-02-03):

Video to adjust the Top is down

apgrc, 2025-02-03:
The video explaining how to adjust the top in the FAQ section is down:

https://github.com/ploopyco/adept-trackball/wiki/Ploopy-Adept-Trackball-Kit-Assembly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

kaaalto, 2025-03-14:
I'm having this problem, and there doesn't seem to be any obvious way to do the adjustments. Could you please reupload the video soonish, or add written instructions?

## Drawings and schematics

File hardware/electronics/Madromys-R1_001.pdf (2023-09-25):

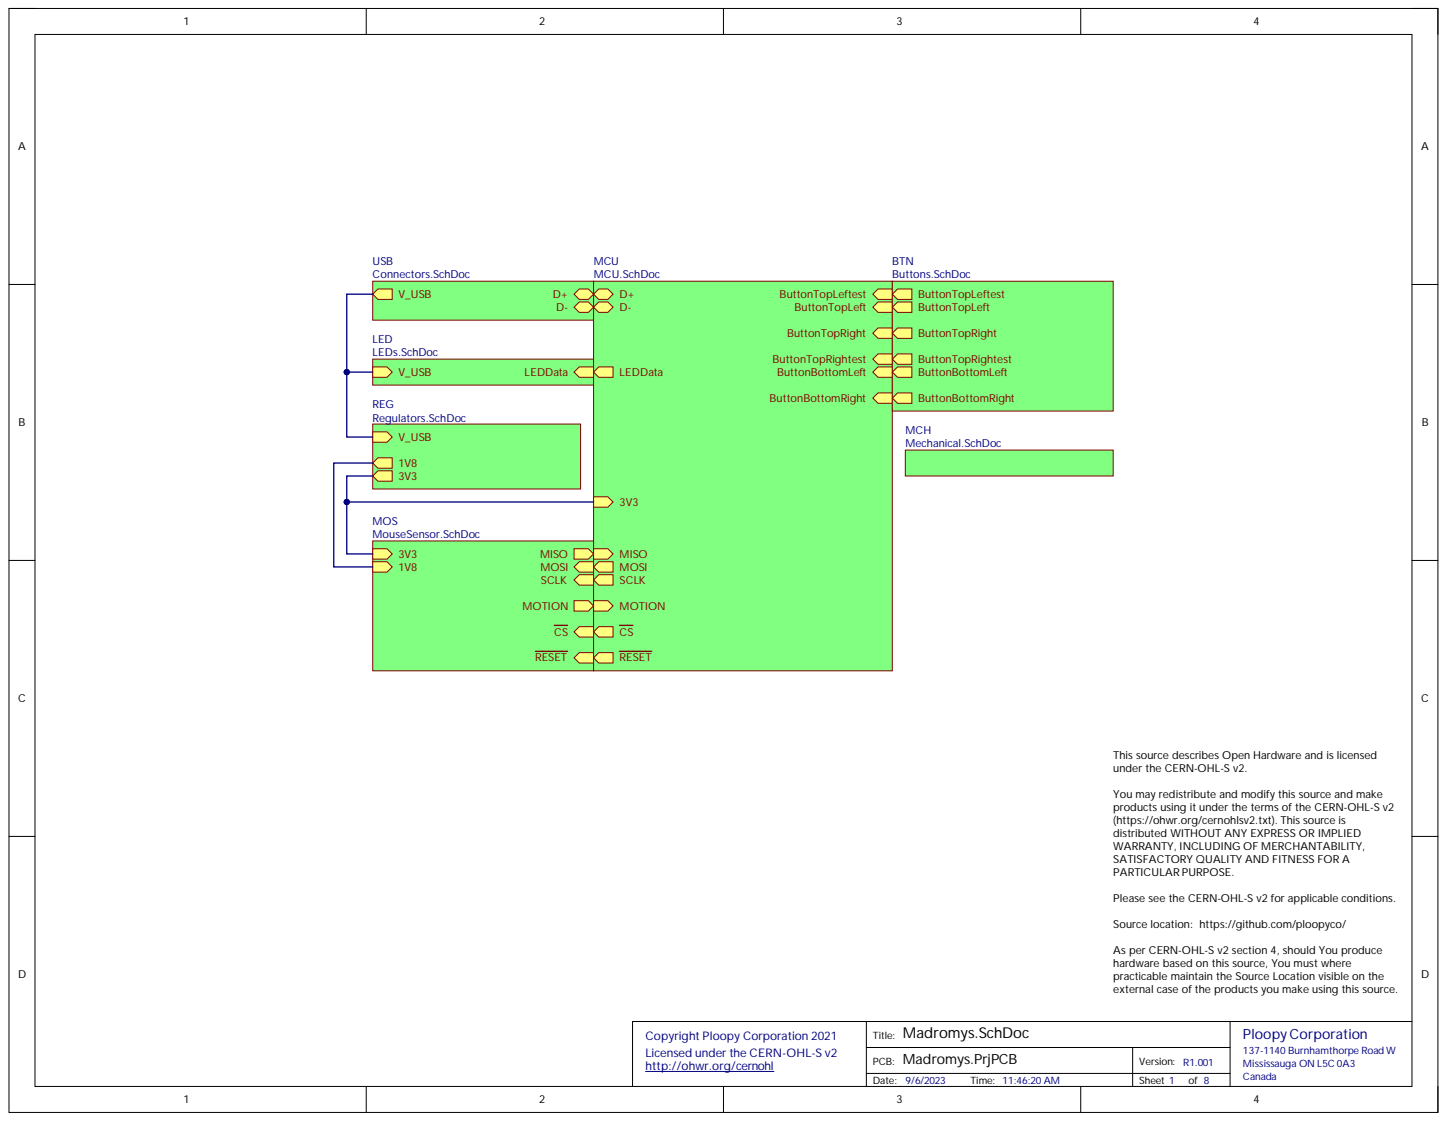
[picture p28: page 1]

This source describes Open Hardware and is licensed
under the CERN-OHL-S v2.

You may redistribute and modify this source and make
products using it under the terms of the CERN-OHL-S v2
(https://ohwr.org/cernohlsv2.txt). This source is
distributed WITHOUT ANY EXPRESS OR IMPLIED
WARRANTY, INCLUDING OF MERCHANTABILITY,
SATISFACTORY QUALITY AND FITNESS FOR A
PARTICULAR PURPOSE.

Please see the CERN-OHL-S v2 for applicable conditions.

Source location: https://github.com/ploopyco/

As per CERN-OHL-S v2 section 4, should You produce
hardware based on this source, You must where
practicable maintain the Source Location visible on the
external case of the products you make using this source.

Copyright Ploopy Corporation 2021
Licensed under the CERN-OHL-S v2
http://ohwr.org/cernohl

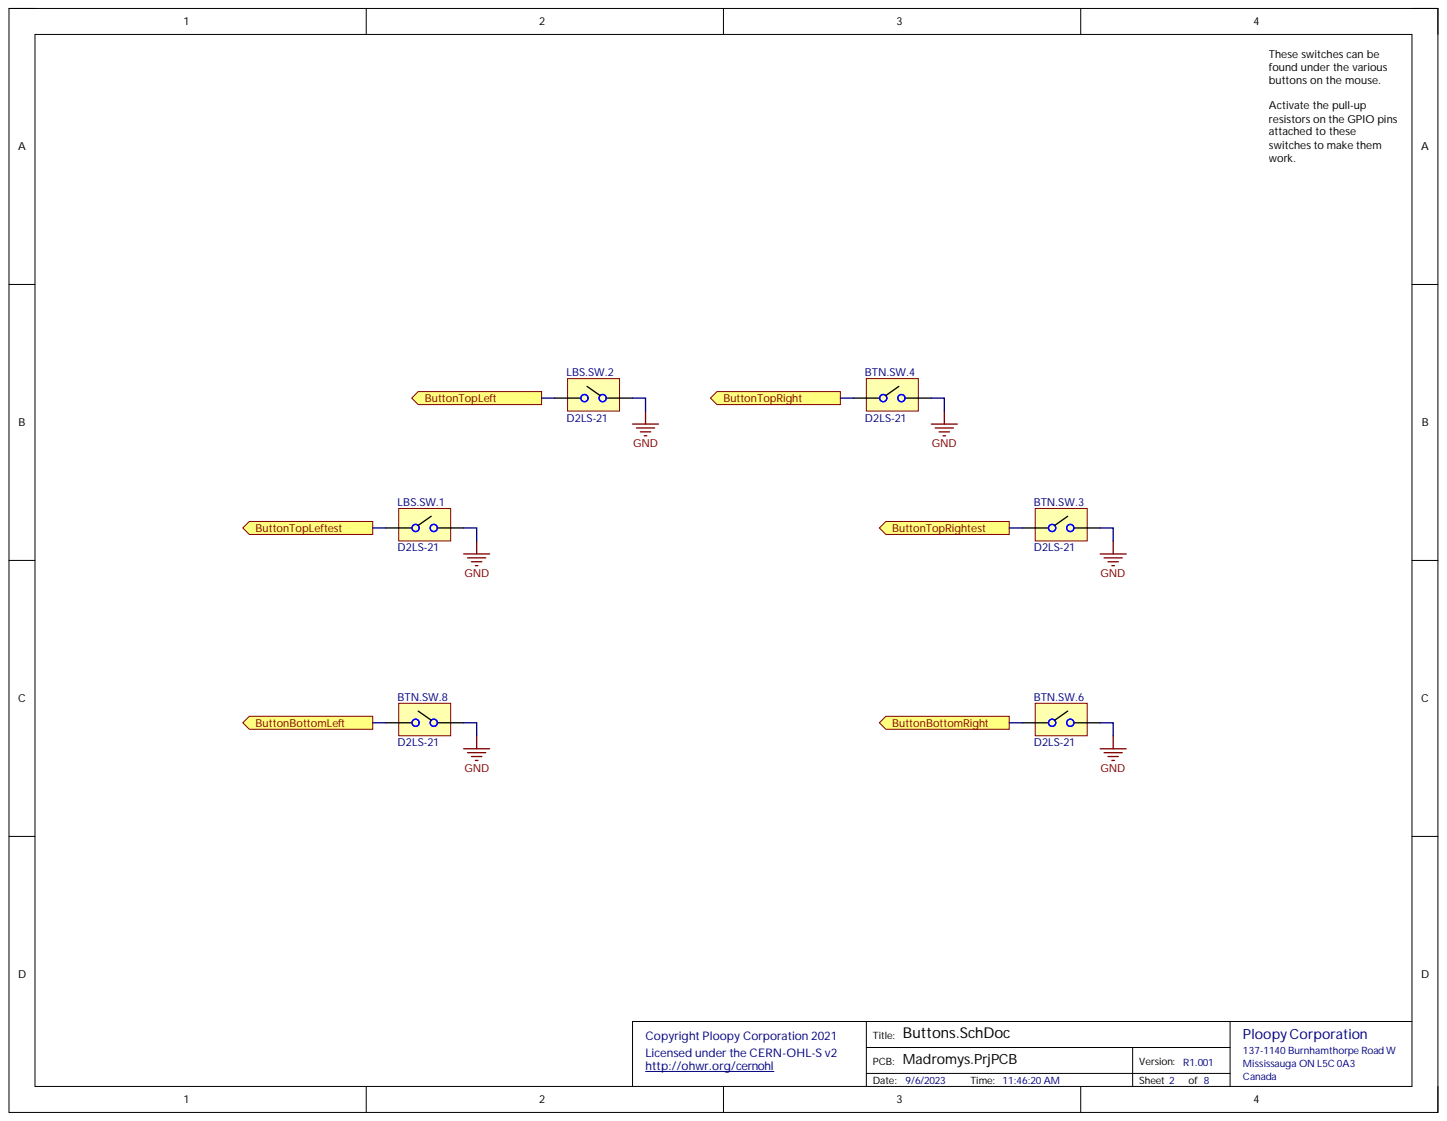
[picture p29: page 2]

These switches can be
found under the various
buttons on the mouse.

Activate the pull-up
resistors on the GPIO pins
attached to these
switches to make them
work.

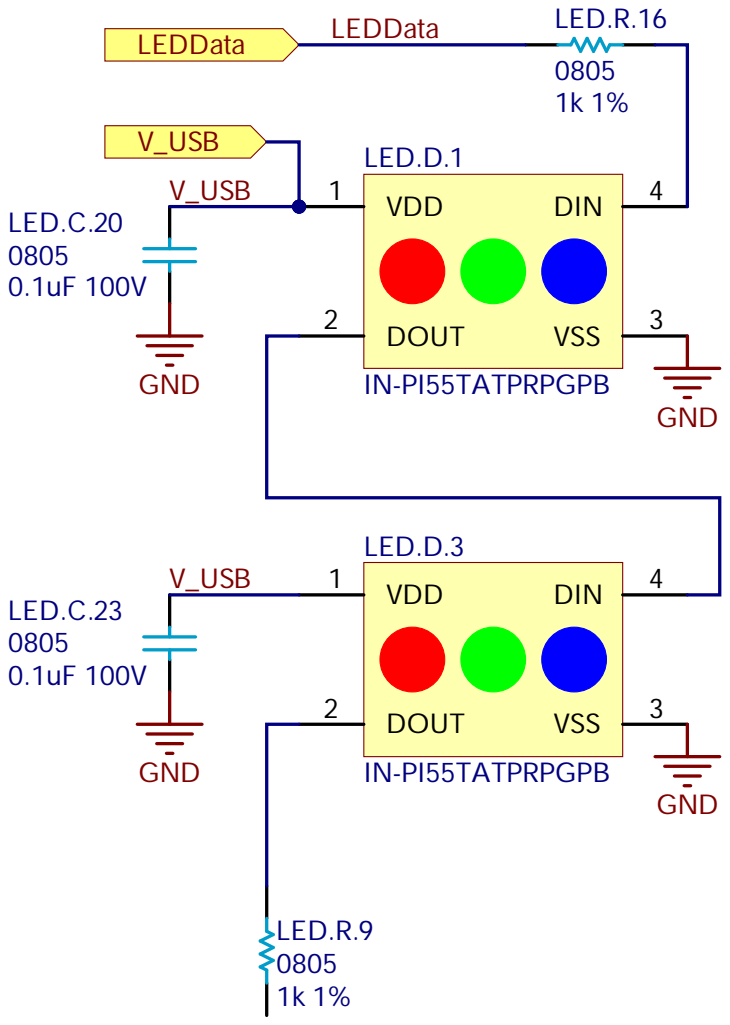
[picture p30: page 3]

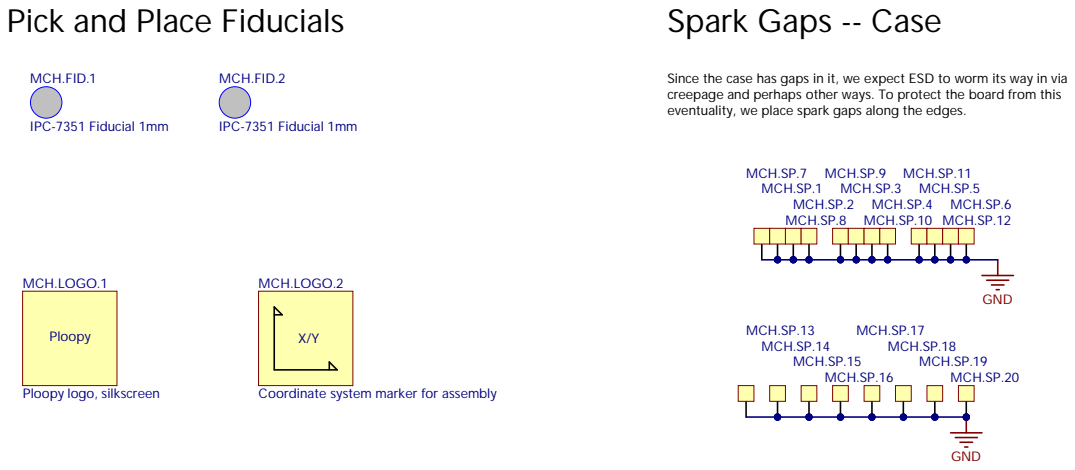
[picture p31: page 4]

Pick and Place Fiducials

Spark Gaps -- Case MCH.SP.7 MCH.SP.1 MCH.SP.8 MCH.SP.2 MCH.SP.9 MCH.SP.3 MCH.SP.10 MCH.SP.4 MCH.SP.1

Since the case has gap
creepage and perhap
eventuality, we place s

s other ways. To protect the board from this
park gap

pect ESD to worm its way in via

Coordinate system marker for assem

Cop
Licensed under the CE
http

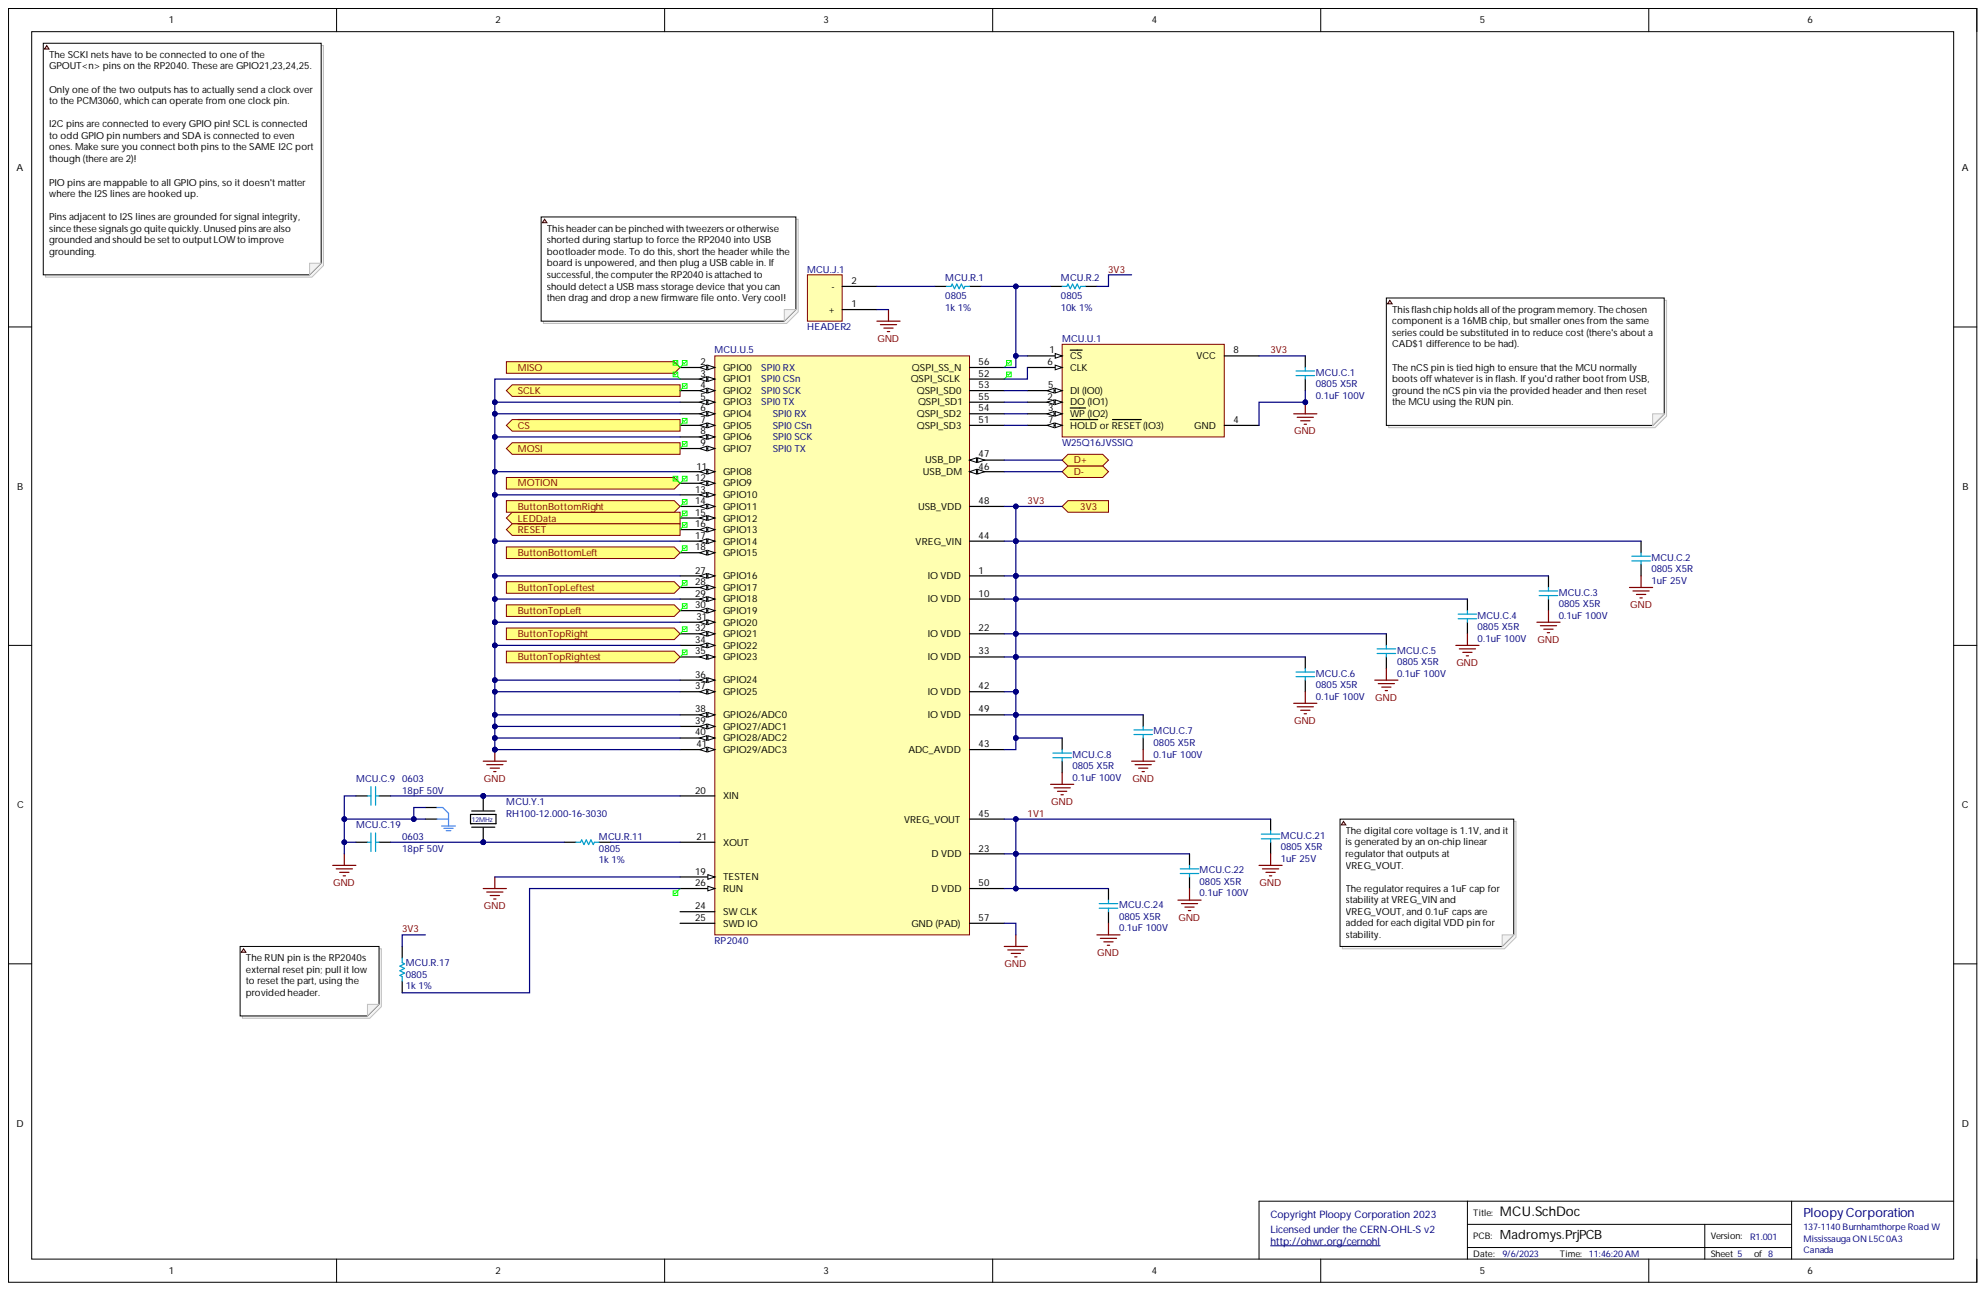
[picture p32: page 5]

The SCKI nets ha

SCLK MISO MOTI 6 | 3

Cop y rig h t Ploop y Cor pora tion 2 02 3 Lice n s e d u n d e r t h e CE R N -OH L -S v 2 h t t p : //ohwr .org /ce r noh l | T i t l e : MC U.S c h Doc | Plo opy C o rpo ra t i o n 1 3 7-1 1 40 B u r n h a m t hor p e Roa d W M i ssi ssa u g a O N L 5C 0A 3 C a n a d a

PC B : Madr omy s.P rj PC B | V e rsion : R 1 . 001

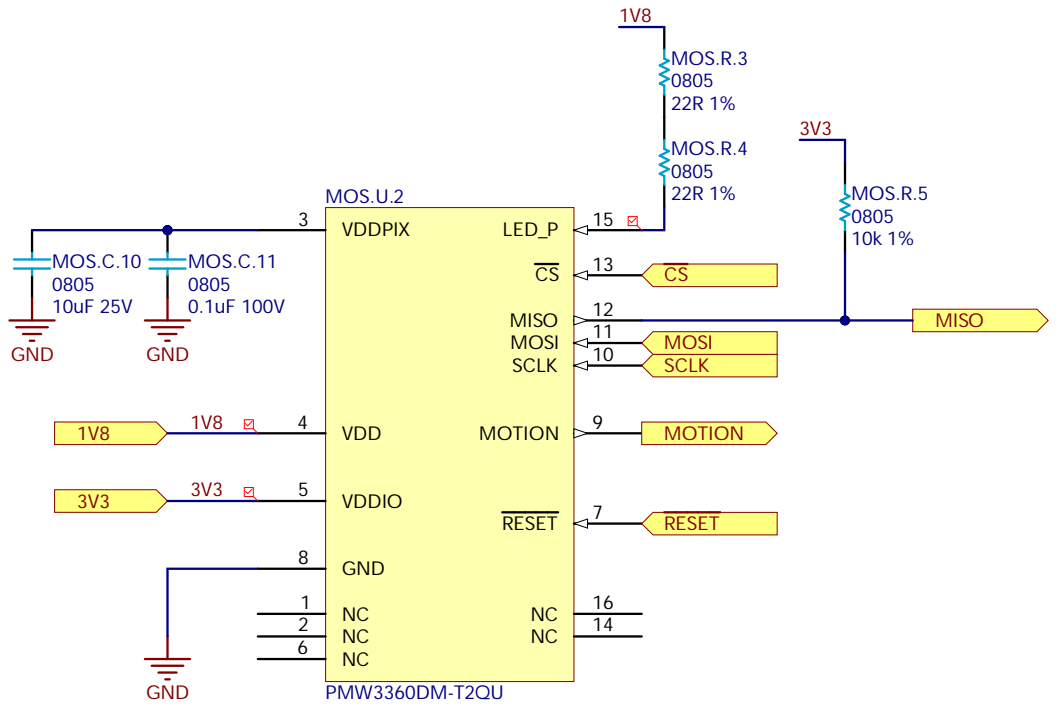
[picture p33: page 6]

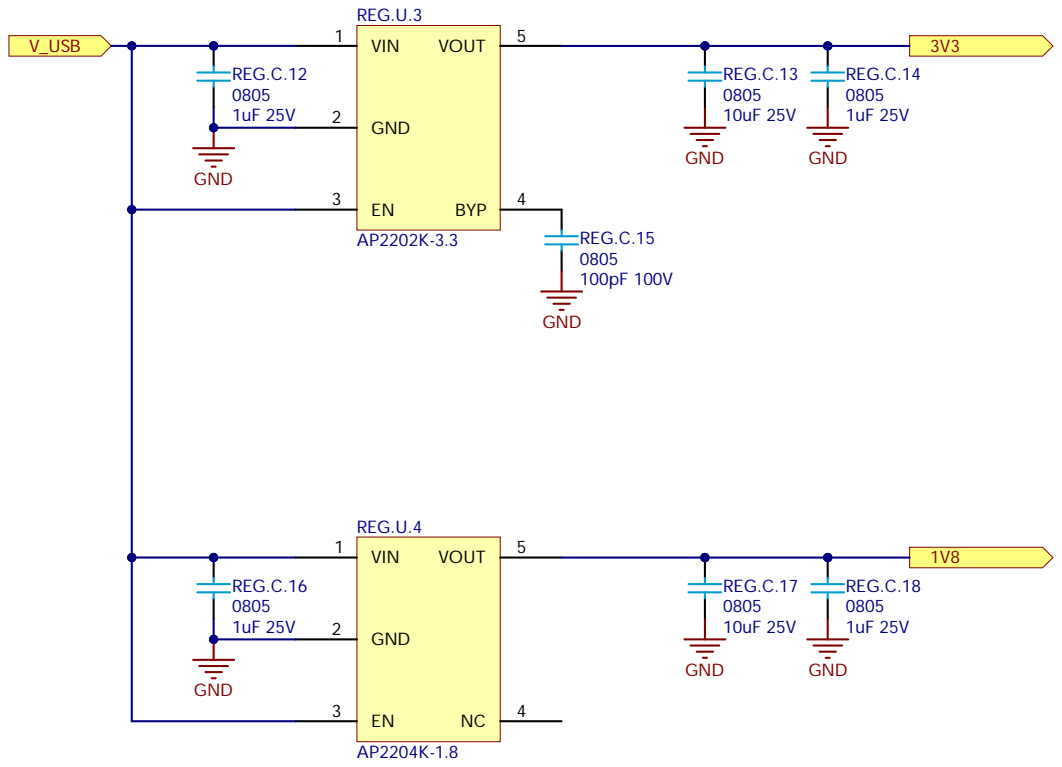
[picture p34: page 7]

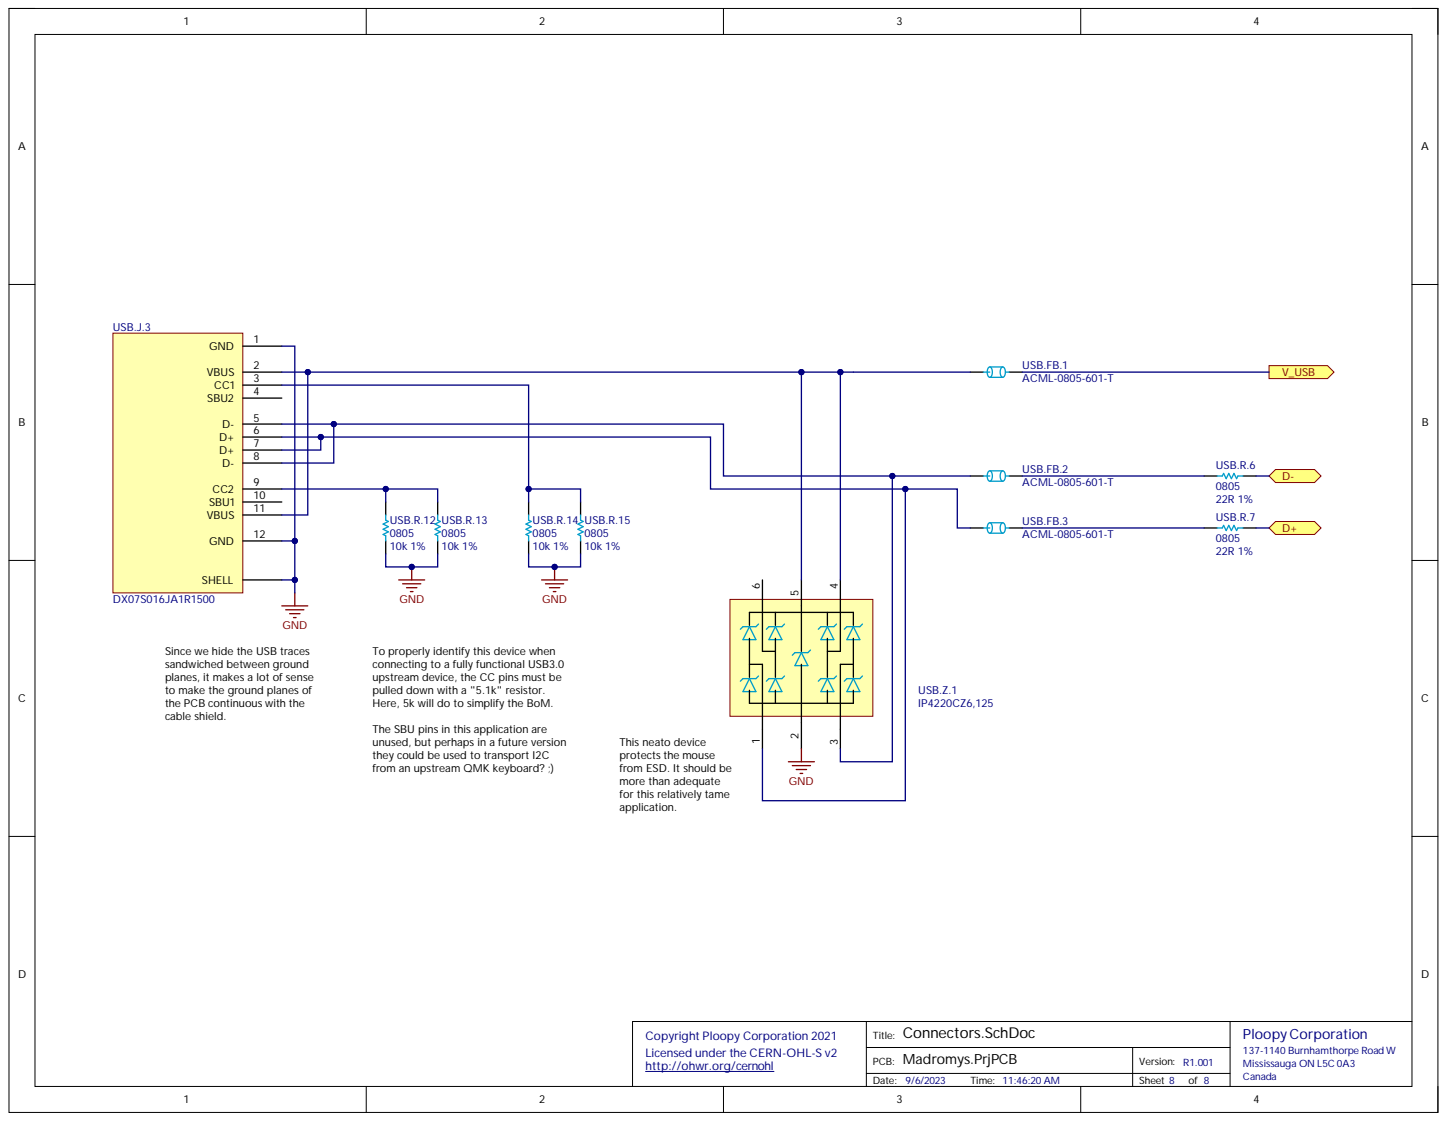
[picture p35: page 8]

Since we hide the USB traces sandwiched between ground planes, it makes a lot of sense

To properly identify this device when
connecting to a fully functional USB3.0
pulled down with a "5.1k" resistor.
Here, 5k will do to sim

to make the ground planes of
the PC
cable shield

The SB
unused, but perhap
they could be used to trans
from an up

U pins in this ap

This neato device protects the mouse

from ESD. It should be more than adequate

for this relatively tame

Cop
Licensed under the CE
http

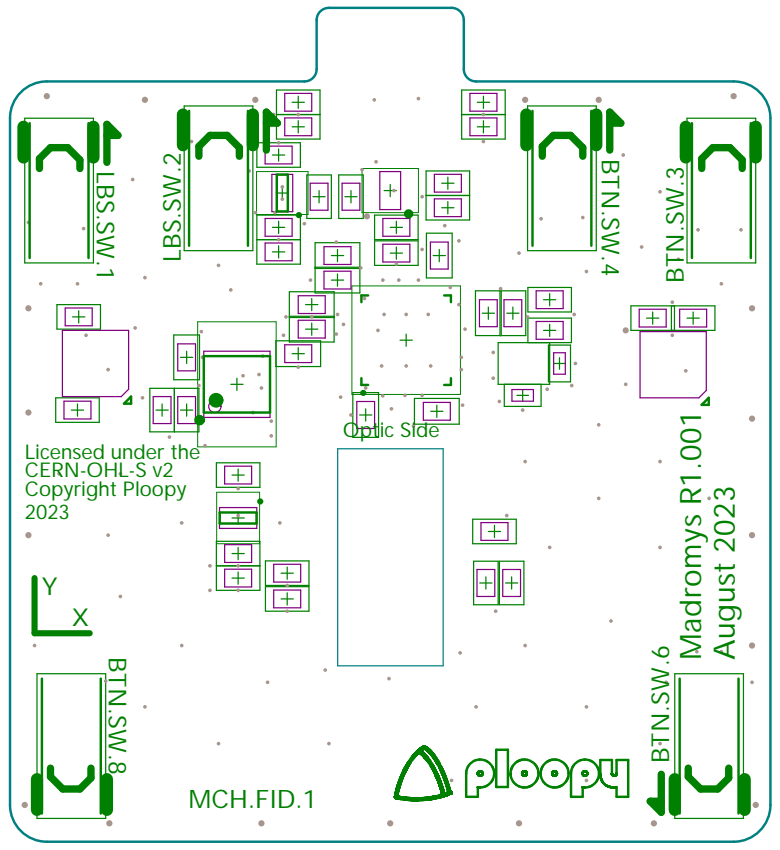
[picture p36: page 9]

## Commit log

2023-09-25 Added initial (no revision markers) mechanical files.
    [AdeptBodyParts.STEP]
2023-09-25 Added R1.001 electrical files, including PDF schematics.
    [Buttons.SchDoc, Chip_Passives.PcbLib, Chip_Passives.SchLib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]
2023-09-27 added 3mf
    [AdeptBodyParts.3mf]
2023-11-30 added firmwares
    Added STL file for printing body parts.
    redid uf2s; moved files to be more clear in directory structure
    updated firmwares to include a liftoff fix
    updated case files to rev3
    [Adept-Rev3.3mf, Adept-Rev3.STEP, AdeptBodyParts.3mf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]
2024-01-16 add f3z file, update readme
    [adept-btu-top-v1.f3z]
